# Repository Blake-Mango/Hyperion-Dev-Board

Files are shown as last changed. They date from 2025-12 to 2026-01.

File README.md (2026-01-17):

# Hyperion-Dev-Board

s a simple dev board that I made for Hack Club Blueprint. It has everything that I would want on a dev board—lots of GPIOs, plenty of grounds, and some other useful features (listed below). This was a fun and pretty easy project to make once I started to understand what I needed to do. It ended up being foundational to my ability to design PCBs, and it showed me how much I enjoy this kind of work. I hope I’ll be able to make even more dev boards later in life, and I’m definitely planning to try some other PCB ideas on Blueprint soon.

# Features
1. The RP2040 is the brain of this project handling all of the processing
2. this uses the W25Q16JVZPIQ with a whopping 16-Megabit flash menmory
3. Usbc this is just a normal USB-C Receptical to send data and also power 
4. one pin for 5v power and another pin for 3v power 
5. 9 pins for ground to make it easy to ground everything you need to 
6. this board comes wih 29 gpio pins 4 of which are dual use for analog inputs (ADC pins)
7. also on this board is an led to make it easy to check if the board is powered on od if there any any problems also to help debug or even program
8. and finaly a button to enter into BOOTSEL mode so you can program you board.

# schematic


# PCB Layout
### Front:


### Back:


# Heres what it looks like when made
top side dev
Bottom side dev

# Demo
here is a short code that was made to just rotate the color of the onboard neopixel led

https://github.com/user-attachments/assets/beb6644e-a9f9-4d21-ad0d-ccec5cd91aba

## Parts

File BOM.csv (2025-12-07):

name | Type | footprint | Quantity | Quantity | Supplier | cost | Link
Capacitors | 0.1uF | C_0402_1005Metric | CL05B104KO5NNNCC1525 100nF 16V X7R ±10% 0402 Multilayer Ceramic Capacitors MLCC - SMD/SMT ROHS | 11 | JLCPCB | $0.04
Capacitors | 1uF | C_0402_1005Metric | CL05A105KA5NQNCC52923 1uF 25V X5R ±10% 0402 Multilayer Ceramic Capacitors MLCC - SMD/SMT ROHS | 2 | JLCPCB | $0.06
Capacitors | 10uF | C_0603_1608Metric | CL10A106KP8NNNCC19702 10V 10uF X5R ±10% 0603 Multilayer Ceramic Capacitors MLCC - SMD/SMT ROHS | 2 | JLCPCB | $0.11
Capacitors | 33pF | C_0402_1005Metric | 0402CG330J500NTC1562 33pF 50V C0G ±5% 0402 Multilayer Ceramic Capacitors MLCC - SMD/SMT ROHS | 2 | JLCPCB | $0.02
led | SK6812MINI | LED_SK6812MINI_PLCC4_3.5x3.5mm_P1.75mm | SK6812MINI-EC5149201 -40℃~+85℃ 0.6mA 1.78mm 120° 1kHz 2.8mm 2000V 3.2mm 3.7V~5.5V 800Kbit/s G:815mcd~1275mcd R:620nm~625nm Semi-transparent lens SMD RGB LEDs(Built-in IC) ROHS | 1 | JLCPCB | $0.41
usbc | USB_C_Receptacle_USB2.0_14P | USB_C_Receptacle_HRO_TYPE-C-31-M-12 | TYPE-C-31-M-12C165948 1 16P 5A Female Type-C SMD USB Connectors ROHS | 1 | JLCPCB | $0.34
resistors | 5.1k | R_0402_1005Metric | 0402WGF5101TCEC25905 -55℃~+155℃ 5.1kΩ 50V 62.5mW Thick Film Resistor ±1% ±100ppm/℃ 0402 Chip Resistor - Surface Mount ROHS | 20 | JLCPCB | $0.01
R3,R4 | 27 | R_0402_1005Metric | 0402WGF270JTCEC25100 -55℃~+155℃ 27Ω 50V 62.5mW Thick Film Resistor ±1% ±100ppm/℃ 0402 Chip Resistor - Surface Mount ROHS | 20 | JLCPCB | $0.01
R6,R5 | 1K | R_0402_1005Metric | 0402WGF1001TCEC11702 -55℃~+155℃ 1kΩ 50V 62.5mW Thick Film Resistor ±1% ±100ppm/℃ 0402 Chip Resistor - Surface Mount ROHS | 20 | JLCPCB | $0.01
R7 | 10K | R_0402_1005Metric | 0402WGF1002TCEC25744 -55℃~+155℃ 10kΩ 50V 62.5mW Thick Film Resistor ±1% ±100ppm/℃ 0402 Chip Resistor - Surface Mount ROHS | 20 | JLCPCB | $0.01
Button | SW_Push | SW_Push_SPST_NO_Alps_SKRK | TS-1088-AR02016C720477 -30℃~+80℃ 1.6N 100,000 Cycles 12V 2mm 3mm 4mm 50mA Black Round Button SMD(SMT) Tab SPST Surface Mount,Vertical Without Bracket SMD,4x3mm Tactile Switches ROHS | 6 | JLCPCB | $0.26
microproscesors | RP2040 | QFN-56-1EP_7x7mm_P0.4mm_EP3.2x3.2mm | RP2040C2040 12bit 133MHz 30 LQFN-56(7x7) Microcontrollers (MCU/MPU/SOC) ROHS | 2 | JLCPCB | $1.83
Flash memory | W25Q16JVZPIQTR | Winbond_USON-8-1EP_3x2mm_P0.5mm_EP0.2x1.6mm | W25Q16JVUXIQC2843335 -40℃~+85℃ 100,000 Cycles 10uA 133MHz 16Mbit 2.7V~3.6V 20 Years 3ms SPI USON-8-EP(2x3) NOR FLASH ROHS | 2 | JLCPCB | $1.17
LDO | MCP1700x-330xxTT | SOT-23 | MCP1700T-3302E/TTC39051 -40℃~+125℃@(Tj) 1 1.6uA 178mV@(250mA) 250mA 3.3V 44dB@(100Hz) 6V Fixed Over Temperature Protection Positive SOT-23 Voltage Regulators - Linear, Low Drop Out (LDO) Regulators ROHS | 5 | JLCPCB | $1.97
Crystal | 12MHz | Crystal_SMD_3225-4Pin_3.2x2.5mm | X322512MSB4SIC9002 -40℃~+85℃ 12MHz 20pF Crystal Oscillator ±10ppm ±20ppm SMD3225-4P Crystals ROHS | 6 | JLCPCB | $0.39
Header Pins | Conn_01x20 | PinHeader_1x20_P2.54mm_Vertical | 2.54-1*20P直针C50981 -40℃~+105℃ 1 1x20P 2.54mm 20P 3A Black Brass Pin Header Through Hole Plugin,P=2.54mm Pin Headers ROHS | 2 | Ali Express | $1.00 | https://www.aliexpress.us/item/3256806029889881.html?mp=1
Header Pins | Conn_01x03 | PinHeader_1x03_P2.54mm_Vertical | 1.27-1*3P针C24980 -55℃~+105℃ 1 1.27mm 1mm 1x3P 2.3mm 3A 3P 3mm Black Brass Pin Header Through Hole Plugin,P=1.27mm Pin Headers ROHS | 1 | Ali Express | Comes with above | https://www.aliexpress.us/item/3256806029889881.html?mp=1

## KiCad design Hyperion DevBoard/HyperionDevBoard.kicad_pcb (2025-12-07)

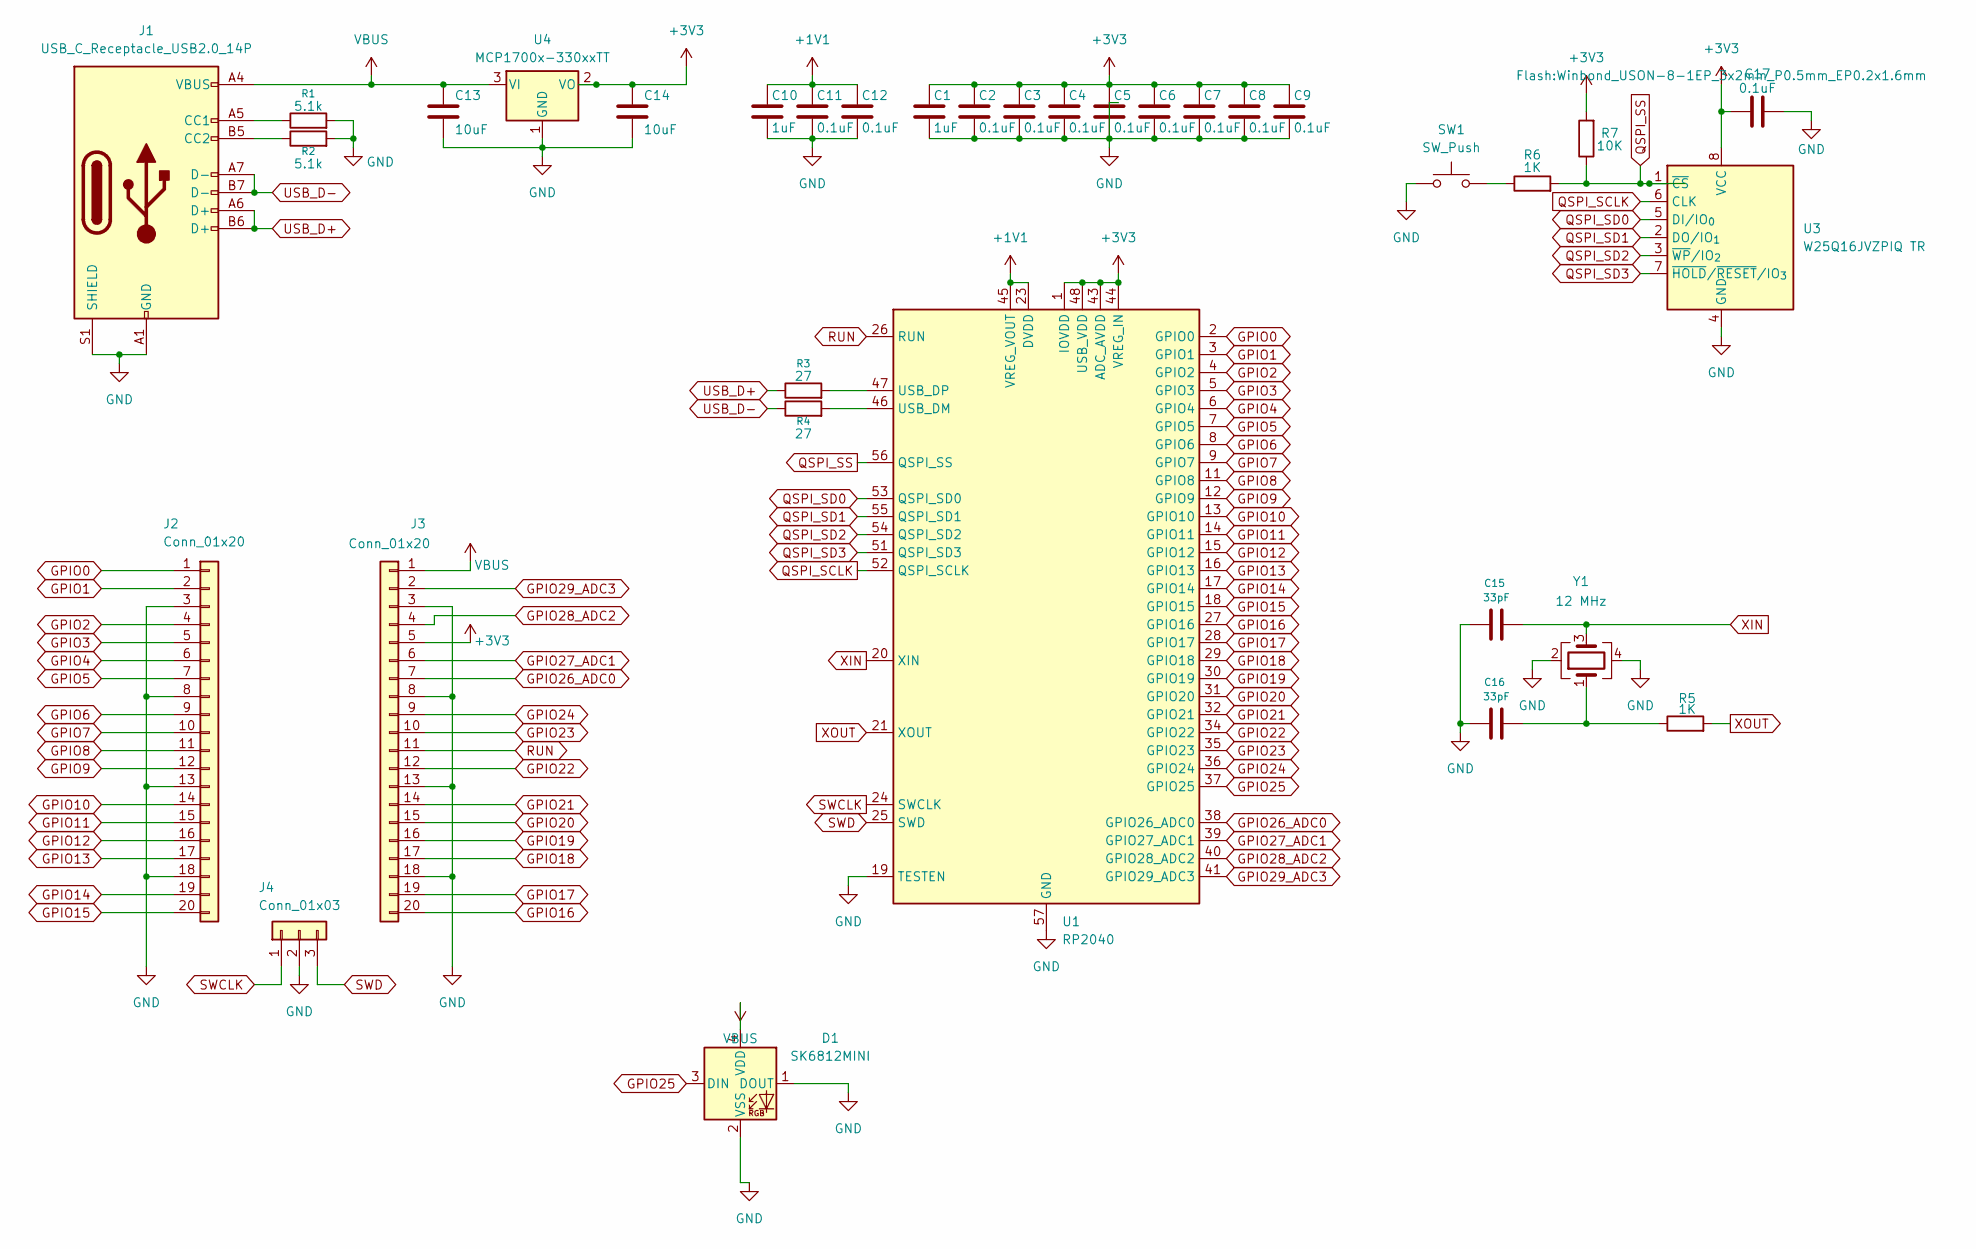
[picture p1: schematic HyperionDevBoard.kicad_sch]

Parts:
C1, C10: 1uF; C_0402_1005Metric
C2, C3, C4, C5, C6, C7, C8, C9, C11, C12, C17: 0.1uF; C_0402_1005Metric
C13, C14: 10uF; C_0603_1608Metric
C15, C16: 33pF; C_0402_1005Metric
D1: SK6812MINI; MX_SK6812MINI-E
J1: USB_C_Receptacle_USB2.0_14P; USB_C_Receptacle_HRO_TYPE-C-31-M-12
J2, J3: Conn_01x20; PinHeader_1x20_P2.54mm_Vertical
J4: Conn_01x03; PinHeader_1x03_P2.54mm_Vertical
R1, R2: 5.1k; R_0402_1005Metric
R3, R4: 27; R_0402_1005Metric
R5, R6: 1K; R_0402_1005Metric
R7: 10K; R_0402_1005Metric
SW1: SW_Push; SW_Push_SPST_NO_Alps_SKRK
U1: RP2040; QFN-56-1EP_7x7mm_P0.4mm_EP3.2x3.2mm
U3: W25Q16JVZPIQ TR; Winbond_USON-8-1EP_3x2mm_P0.5mm_EP0.2x1.6mm
U4: MCP1700x-330xxTT; SOT-23
Y1: 12 MHz; Crystal_SMD_3225-4Pin_3.2x2.5mm

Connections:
+1V1: C10.1, C11.1, C12.1, U1.23 (DVDD), U1.45 (VREG_VOUT), U1.50 (DVDD)
+3V3: C1.1, C2.1, C3.1, C4.1, C5.1, C6.1, C7.1, C8.1, C9.1, C14.1, C17.1, J3.5, R7.2, U1.1 (IOVDD), U1.10 (IOVDD), U1.22 (IOVDD), U1.33 (IOVDD), U1.42 (IOVDD), U1.43 (ADC_AVDD), U1.44 (VREG_IN), U1.48 (USB_VDD), U1.49 (IOVDD), U3.8 (VCC), U4.2 (VO)
GND: C1.2, C2.2, C3.2, C4.2, C5.2, C6.2, C7.2, C8.2, C9.2, C10.2, C11.2, C12.2, C13.2, C14.2, C15.1, C16.1, C17.2, D1.1 (DOUT), D1.2 (VSS), J1.A1 (GND), J1.A12 (GND), J1.B1 (GND), J1.B12 (GND), J1.S1 (SHIELD), J2.3, J2.8, J2.13, J2.18, J3.3, J3.8, J3.13, J3.18, J4.2, R1.2, R2.2, SW1.1, U1.19 (TESTEN), U1.57 (GND), U3.4 (GND), U4.1 (GND), Y1.2, Y1.4
GPIO0: J2.1, U1.2 (GPIO0)
GPIO1: J2.2, U1.3 (GPIO1)
GPIO2: J2.4, U1.4 (GPIO2)
GPIO3: J2.5, U1.5 (GPIO3)
GPIO4: J2.6, U1.6 (GPIO4)
GPIO5: J2.7, U1.7 (GPIO5)
GPIO6: J2.9, U1.8 (GPIO6)
GPIO7: J2.10, U1.9 (GPIO7)
GPIO8: J2.11, U1.11 (GPIO8)
GPIO9: J2.12, U1.12 (GPIO9)
GPIO10: J2.14, U1.13 (GPIO10)
GPIO11: J2.15, U1.14 (GPIO11)
GPIO12: J2.16, U1.15 (GPIO12)
GPIO13: J2.17, U1.16 (GPIO13)
GPIO14: J2.19, U1.17 (GPIO14)
GPIO15: J2.20, U1.18 (GPIO15)
GPIO16: J3.20, U1.27 (GPIO16)
GPIO17: J3.19, U1.28 (GPIO17)
GPIO18: J3.17, U1.29 (GPIO18)
GPIO19: J3.16, U1.30 (GPIO19)
GPIO20: J3.15, U1.31 (GPIO20)
GPIO21: J3.14, U1.32 (GPIO21)
GPIO22: J3.12, U1.34 (GPIO22)
GPIO23: J3.10, U1.35 (GPIO23)
GPIO24: J3.9, U1.36 (GPIO24)
GPIO25: D1.3 (DIN), U1.37 (GPIO25)
GPIO26_ADC0: J3.7, U1.38 (GPIO26_ADC0)
GPIO27_ADC1: J3.6, U1.39 (GPIO27_ADC1)
GPIO28_ADC2: J3.4, U1.40 (GPIO28_ADC2)
GPIO29_ADC3: J3.2, U1.41 (GPIO29_ADC3)
unnamed: C16.2, R5.1, Y1.1
unnamed: J1.A5 (CC1), R1.1
unnamed: J1.B5 (CC2), R2.1
unnamed: R6.1, SW1.2
unnamed: R4.2, U1.46 (USB_DM)
unnamed: R3.2, U1.47 (USB_DP)
QSPI_SCLK: U1.52 (QSPI_SCLK), U3.6 (CLK)
QSPI_SD0: U1.53 (QSPI_SD0), U3.5 (DI/IO_{0})
QSPI_SD1: U1.55 (QSPI_SD1), U3.2 (DO/IO_{1})
QSPI_SD2: U1.54 (QSPI_SD2), U3.3 (~WP/IO_{2})
QSPI_SD3: U1.51 (QSPI_SD3), U3.7 (~HOLD/~RESET/IO_{3})
QSPI_SS: R6.2, R7.1, U1.56 (QSPI_SS), U3.1 (~CS)
RUN: J3.11, U1.26 (RUN)
SWCLK: J4.1, U1.24 (SWCLK)
SWD: J4.3, U1.25 (SWD)
USB_D+: J1.A6 (D+), J1.B6 (D+), R3.1
USB_D-: J1.A7 (D-), J1.B7 (D-), R4.1
VBUS: C13.1, D1.4 (VDD), J1.A4 (VBUS), J1.A9 (VBUS), J1.B4 (VBUS), J1.B9 (VBUS), J3.1, U4.3 (VI)
XIN: C15.2, U1.20 (XIN), Y1.3
XOUT: R5.2, U1.21 (XOUT)

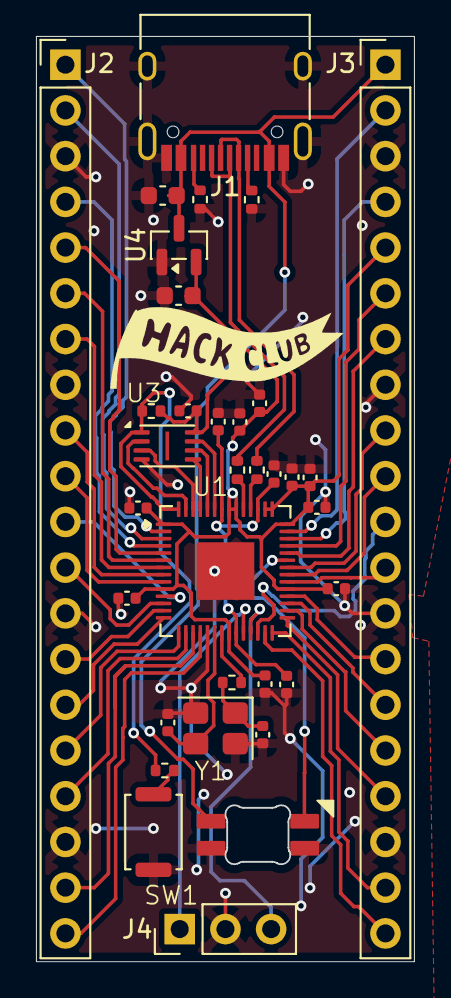
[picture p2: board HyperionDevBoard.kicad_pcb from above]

Board: 2 copper layers, 21.0 x 51.4 mm, 34 parts (1 on the bottom side), 53 nets.

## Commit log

2025-12-06 Update and rename HyperionDevBoard_Pos - HyperionDevBoard.csv to BOM.csv
    [BOM.csv]
2025-12-07 Revise README with project overview and features
    Updated the README to provide a clearer description of the Hyperion Dev Board and its features.
2025-12-07 Update and rename BOM - HyperionDevBoard.csv to BOM.csv
    [BOM.csv]
2025-12-07 Add PCB Layout section with images
    Added PCB layout images for front and back views.
2025-12-07 Fix BOM.csv formatting and add missing entries
    [BOM.csv]
2026-01-17 Update README with demo link for neopixel LED
    Added a link to a demo for color rotation of neopixel LED.
